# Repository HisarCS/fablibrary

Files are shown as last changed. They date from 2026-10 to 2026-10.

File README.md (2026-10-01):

# FabLibrary – Hisar FabLab

An open design library for the K12 Fab STEAM projects of Hisar IdeaLab FabLab.
Every project is documented here with its laser-cut, 3D-printed, electronics and teaching materials.

**Website:** https://hisarcs.github.io/fablibrary/

## Projects

| Project | Level | Status |
|---|---|---|
| [Welcome Space](projects/welcome-space/) – LED-lit spaceship (Mission 01) | Grade 4, 60 min | v1 prototype |

## Quick start

```bash
pip install -r requirements.txt
python projects/welcome-space/generators/build.py   # regenerate design files
mkdocs serve                                        # preview the site at http://127.0.0.1:8000
```

## License

- Design files and documentation: CC BY-SA 4.0 ([LICENSE-DESIGNS.md](LICENSE-DESIGNS.md))
- Code (generators, scripts): MIT ([LICENSE](LICENSE))

How to contribute: [CONTRIBUTING.md](CONTRIBUTING.md)

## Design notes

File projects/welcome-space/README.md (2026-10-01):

# Welcome Space – Mission 01

An LED-lit, personalized desktop spaceship. Grade 4, 60 minutes, ~140 students.

| Folder | Contents |
|---|---|
| `laser/` | Base plate, panel, wing, comb test (SVG, mm) |
| `3d/` | Nose cone, diffuser (OpenSCAD, parametric) |
| `drawings/` | Dimensioned technical drawings, assembly |
| `electronics/` | Electronics notes and test form |
| `stickers/` | BN-20 sticker files |
| `teaching/` | Lesson plan, troubleshooting card |
| `tests/` | Test photos and notes |
| `generators/` | Scripts that generate every SVG |
| `kit-list.md` | Parts per kit and post-test parameter map |

To regenerate (from repo root): `python projects/welcome-space/generators/build.py`

Website: https://hisarcs.github.io/fablibrary/projects/welcome-space/

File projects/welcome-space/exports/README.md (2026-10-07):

# Exports

Generated by `scripts/export_formats.py`. Do not edit these files by hand: edit the sources and run the script again.

| Folder | For | Notes |
|---|---|---|
| `inkscape/` | Inkscape | Named layers, millimetre display units |
| `illustrator/` | Adobe Illustrator | Plain SVG, each group becomes a layer |
| `dxf/` | Laser software, LightBurn, xTool, Epilog, any CAD | Layers CUT (red) and ENGRAVE (black), millimetres |
| `web/` | The website | Thicker lines and a white background, for thumbnails |
| `onshape/` | Onshape (and any CAD) | Flat profiles and the half-profiles of the revolved parts, for sketches. STL cannot be edited as CAD. |

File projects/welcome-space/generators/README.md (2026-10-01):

# Generators

All laser SVGs and drawings are generated by these scripts. Do not edit the SVGs by hand.

| Script | Generates | Key parameters |
|---|---|---|
| `base_diffuser_comb.py` | base plate laser, comb test, base + diffuser drawing | `SLOT_W`, `SLOT_L`, `WSLOT_L` |
| `panel_nosecone.py` | panel laser, panel + nose cone drawing, nose cone SCAD | panel profile `P` |
| `wing.py` | wing laser and drawing | wing profile `K` |
| `assembly.py` | assembly drawing | – |
| `printables.py` | GS-24 copper band, BN-20 sticker sheet, troubleshooting card | band layout, sticker positions |
| `student_card.py` | picture-first student step card (A4) | tile drawings, text |
| `model3d.py` | 3D preview meshes (STL) and web viewer data | needs numpy, scipy, matplotlib; not run by `build.py` |
| `model_b.py` | Model B (LEDs outside): laser SVGs, drawing, nose cone, preview STLs, viewer data | needs numpy, scipy, matplotlib; not run by `build.py` |
| `hero.py` | day/night and personalization illustrations | colors, `deco` styles |

`3d/v1_diffuser.scad` is a hand-maintained parametric file.

Run: `python projects/welcome-space/generators/build.py`

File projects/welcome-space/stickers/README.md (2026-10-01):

# Sticker set (BN-20)

One sheet per student, 15–20 pieces: 3 windows, 3 planets, 4–5 stars, 3 wing patterns, 1–2 stripes, 1 blank name label (optional).

Rules: no stickers on press-fit tab areas, on the nose cone/diffuser, or on the electronics area. Matte vinyl, kiss-cut.

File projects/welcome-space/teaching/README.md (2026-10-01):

# Teaching materials

Lesson plan: `docs/projects/welcome-space/lesson.md`

Troubleshooting card (5 steps): Battery → Switch → LED direction → Tape contact → Leg contact

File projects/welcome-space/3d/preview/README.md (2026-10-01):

# Preview meshes (not for printing)

These STL files are generated from the same numbers as the drawings by `generators/model3d.py`. They exist so that anyone can look at the design in a 3D viewer, a slicer preview or the website explorer.

- `v1_assembly_preview.stl`: the whole ship, assembled.
- One STL per part type: base plate, panel (1 of 3), wing (1 of 3), nose cone, diffuser.

They are **simplified**: the nose-cone slots and the diffuser switch window are not modeled. **Print from the OpenSCAD files** (`../v1_nose_cone.scad`, `../v1_diffuser.scad`). To export real print STLs:

```bash
sudo apt install openscad
openscad -o v1_nose_cone.stl ../v1_nose_cone.scad
openscad -o v1_diffuser.stl ../v1_diffuser.scad
```

Regenerate the previews (needs `numpy`, `scipy` and `matplotlib`):

```bash
pip install numpy scipy matplotlib
python projects/welcome-space/generators/model3d.py
```

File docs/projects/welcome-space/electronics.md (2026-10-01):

# Electronics

**One rule:** if the electronics are solid, everything else is artistic.

## Architecture
CR2032 → holder with cover and switch → 2 straight copper rails (+ on top, − on bottom) → 3 LEDs (2 white + 1 color). Everything sits on the **bottom face** of the base plate, inside the exhaust diffuser. Panels and nose cone carry no electrical connections.

## Rules
- Rails are 54 × 5 mm with an **8 mm** gap; extra tape pieces are 6 mm max (short-circuit prevention).
- LED legs: long (+) on the top rail, short (−) on the bottom rail. The leg lies flat on the rail and a short piece of copper tape goes on top (**sandwich joint**).
- The copper tape adhesive must be **conductive**: check with a multimeter from adhesive side to top side.
- If resistors are needed, assistants pre-solder them, not students. Values are set by testing; white/blue LEDs may be brighter without resistors on a CR2032.
- The internal resistance of a CR2032 limits short-circuit current; if switching to stronger cells (AAA), add a resettable fuse.

## Acceptance test
1. Open-circuit and loaded voltage on a fresh cell
2. Series current for each LED type
3. Cell voltage and brightness after 1 hour
4. All three LEDs visible from 3 m in a dark room
5. Switch cycled 100 times
6. 10 different people build the same circuit: **10/10 must work**

## Troubleshooting order
Battery → Switch → LED direction → Tape contact → Leg contact

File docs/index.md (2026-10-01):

# FabLibrary

An open design library for the K12 students of Hisar IdeaLab FabLab. Every project is a **mission**: first assemble, then modify, then design your own.

**Assemble → Modify → Design → Fabricate → Test → Improve**

Welcome Space spaceship with stickers, day and dark room

*Illustration of a finished ship.*

<div class="grid cards" markdown>

-   :material-rocket-launch: **Welcome Space** · Mission 01

    ---

    An LED-lit, personalized desktop spaceship. Laser cutting, 3D printing and solderless electronics in 60 minutes.

    Grade 4 · v1 prototype

    [:octicons-arrow-right-24: Go to project](projects/welcome-space/index.md)

-   :material-lock-clock: **Mission 02 – Modify**

    ---

    Design your own wing, cut it on the laser, attach it to your ship.

    Coming soon

-   :material-gamepad-variant: **Play the game** · Mission Control

    ---

    Six short missions on the iPad: match parts to machines, light the LEDs, hunt bugs and design your own ship.

    [:octicons-arrow-right-24: Play](projects/welcome-space/play.md)

</div>

## The path

| Mission | Idea | Status |
|---|---|---|
| 01 Assemble | Build and light your own spaceship from ready-made digital-fabrication parts | v1 prototype |
| 02 Modify | Change a part: your own wing shape | Planned |
| 03 Design | Design a part in CAD from scratch | Planned |
| 04 Fabricate | Cut and print your own design | Planned |
| 05 Improve | Test, find what to fix, make version 2 | Planned |

*Your first design does not have to be your last design.*

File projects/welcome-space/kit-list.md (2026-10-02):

# v1 Spaceship – Kit List and Parameter Map

Target: 140 students + spares and prototypes = **160 kits**. All values are v1 drafts and will be updated after testing.

## 1. Parts per kit

| # | Part | Qty/kit | Process | File | Total (160) |
|---|---|---|---|---|---|
| 1 | Base plate Ø110 | 1 | Laser, 3 mm birch | `laser/v1_base_plate_laser.svg` | 160 |
| 2 | Body panel | 3 | Laser, 3 mm birch | `laser/v1_panel_laser.svg` | 480 |
| 3 | Wing | 3 | Laser, 3 mm birch | `laser/v1_wing_laser.svg` | 480 |
| 4 | Nose cone | 1 | 3D, translucent PLA/PETG | `3d/stl/v1_nose_cone.stl` (export of `v1_nose_cone.scad`) | 160 |
| 5 | Exhaust diffuser | 1 | 3D, translucent PLA/PETG | `3d/stl/v1_diffuser.stl` (export of `v1_diffuser.scad`) | 160 |
| 6 | CR2032 holder with cover and switch | 1 | Off the shelf (Motorobit, sample pending) | – | 160 |
| 7 | CR2032 cell | 1 | Off the shelf | – | 160 |
| 8 | 5 mm LED, white | 2 | Off the shelf | – | 320 |
| 9 | 5 mm LED, color | 1 | Off the shelf | – | 160 |
| 10 | Copper rail set (2 rails 54×5 + 6 patches) | 1 | GS-24 cut or by hand | – | 160 |
| 11 | Resistor | 0–3 | Off the shelf, pre-soldered by assistants | Set by testing | TBD |
| 12 | Sticker sheet | 1 | BN-20 print + cut | To be designed | 160 |
| 13 | Double-sided tape (for holder) | 1 piece | Off the shelf | – | 160 |

## 2. Approximate materials (estimates, not measured)

| Material | Per kit | 160 kits |
|---|---|---|
| 3 mm birch plywood | ~0.06 m² (incl. 35% waste) | ~10 m² |
| Translucent filament | ~45 g (nose cone ~22 g + diffuser ~24 g, assuming 100% infill) | ~7.5 kg + test waste → **~9 kg** |
| 5 mm copper tape | ~0.3 m | ~50–60 m |

Print and laser times: **to be measured on the first part**, then split across 17 printers and 3 lasers.

## 3. Per class (outside the kit)

- Multimeter ×3, battery/LED tester ×2–3, tweezers ×5–6
- Spare finished rockets ×5–6
- Spare LEDs, cells, copper tape and stickers (15%)
- Troubleshooting card (5 steps: battery → switch → LED direction → tape contact → leg contact)

## 4. Parameters to change after testing

| Test | Value to measure | File and parameter to change |
|---|---|---|
| Comb test | Best slot width (3.00–3.30) | `generators/base_diffuser_comb.py`: `SLOT_W` (now 3.1) |
| Comb test | Same value | Panel bottom tab 27.8 and wing tab 19.8 (shorten if needed) |
| Nose cone print | Which of 3.2 / 3.3 / 3.4 fits | `3d/v1_nose_cone.scad`: `slotW` |
| Diffuser print | Which of 110.25 / 110.40 / 110.55 fits | `3d/v1_diffuser.scad`: `pocketD` |
| Holder sample | Switch side, height, wire exit | `3d/v1_diffuser.scad`: `winAng`, `winW`, `winZ0`, `winZ1` |
| Electronics bench test | LED type, resistor value, current | This list: #8, #9, #11 |
| Dark room | Does the nose cone glow? | LED direction or `wall` if needed |
| Wing wobble | Does it lean? | Split the wing tab in two |
| Child assembly | Order of steps 4-5-6 | `generators/assembly.py` |

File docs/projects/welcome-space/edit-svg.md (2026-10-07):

# Editing the SVG files

The laser, Roland and drawing files are plain SVG. You can open and edit them in any vector editor. This page shows how to do it safely.

## Which program?

| Program | Cost | Good for |
|---|---|---|
| **Inkscape** | free | Everything on this page. Recommended. Ubuntu: `sudo apt install inkscape` |
| Illustrator, CorelDRAW | paid | Fine, if your laser software is built on them |
| xTool Creative Space, LightBurn | | Open the SVG directly to cut it. Edit in Inkscape first for bigger changes |
| A text editor | free | Change a number or a word. SVG is just text |

## The rules every file follows

| Rule | Why |
|---|---|
| **1 unit = 1 mm.** Size is written in mm (for example `110mm`), and the `viewBox` has the same number. | The file cuts at real size. Keep the document scale at 100%. |
| **Red hairline = cut through.** Line width about 0.1 mm. | Laser software reads thin red as a cut. |
| **Black = engrave.** | Text, marks and guides on the surface. |
| **Magenta `CutContour` = the BN-20 cut line**, with the colors on a separate `PRINT` layer. | The Roland prints the colors and cuts along the magenta line. |
| Each file has named layers: **CUT**, **ENGRAVE** (and **PRINT**, **CUT CONTOUR** for stickers). | Open Inkscape's Layers panel (`Shift+Ctrl+L`) to hide or lock them. |

## Edit, step by step (Inkscape)

1. Open the file. If Inkscape asks about scale, choose the default and keep **mm** as the display unit (Document Properties, `Shift+Ctrl+D`).
2. In the Layers panel, **lock the CUT layer** while you edit the ENGRAVE layer (and the other way round), so you do not move the wrong thing.
3. Make your change. To move or resize something exactly, use the X, Y, W, H boxes in the toolbar, in mm.
4. **Convert text to outlines** before it goes to the machine: select the text, then *Path > Object to Path* (`Shift+Ctrl+C`). Otherwise the machine may use a different font.
5. Save as **Plain SVG** or **Inkscape SVG**, into `projects/welcome-space/custom/` (see below).
6. **Check it** before cutting:

   ```bash
   python scripts/svg_tool.py check projects/welcome-space/custom/your_file.svg
   ```

   It checks scale, colors, line width and text, and says what is wrong.

## Important: where to save your edit

Most SVGs here are **generated** from numbers (`generators/`). If you save your edit over the original, the next rebuild overwrites it.

- **A one-off edit** (a name engraved on one plate, a test piece): save it in **`projects/welcome-space/custom/`** with the name `<original>__custom-<what-you-changed>.svg`. That folder is never overwritten.
- **A real improvement** (a better slot width, a new hole): change the **parameter** in the generator, rebuild, and open an issue. Then every file and the 3D explorer update together.

## Quick fixes in a text editor

| I want to | Change |
|---|---|
| Change the plate diameter | The `r="55"` of the circle in the CUT layer (radius, in mm) |
| Make slots wider | The `height` or `width` of the slot rectangles. The generator parameter is `SLOT_W` |
| Move a label | The `x` and `y` of its `<text>` |
| Hide a layer in the machine software | Delete the layer's `<g> ... </g>` block |

## Check list before you cut

- [ ] `svg_tool.py check` says no errors
- [ ] Measure the finished file's size in the machine software: **110 mm** for a plate, with calipers on the first test piece
- [ ] Text is converted to outlines
- [ ] Red = cut, black = engrave, nothing else
- [ ] First cut on scrap plywood

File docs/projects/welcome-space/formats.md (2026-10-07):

# Files for Inkscape, Illustrator and Onshape

The same designs, in the format your program wants. All of them are generated from the sources by `scripts/export_formats.py`, so they always match. They live in the repository folder [`projects/welcome-space/exports`](https://github.com/HisarCS/fablibrary/tree/main/projects/welcome-space/exports) and in the [Source files](sources.md) ZIP.

## Which folder for which program

| I use | Take the files from | What you get |
|---|---|---|
| **Inkscape** | `exports/inkscape/*.svg` | Named layers (CUT, ENGRAVE, PRINT), millimetre display units |
| **Adobe Illustrator** | `exports/illustrator/*.svg` | Plain SVG. Each group becomes a layer named CUT-..., ENGRAVE-... |
| **Laser software** (Epilog, xTool Creative Space, LightBurn) | `exports/dxf/*.dxf` or the Illustrator SVG | DXF with layers CUT (red) and ENGRAVE (black), in millimetres, text kept as text |
| **Onshape** (or any CAD) | `exports/onshape/*.dxf` | Flat profiles and half-profiles for sketches (see below) |
| **A slicer** (Bambu Studio) | `3d/stl/*.stl` | The print-ready meshes |
| **OpenSCAD** | `3d/*.scad` | The parametric source of the 3D printed parts |

!!! warning "Test one file first"
    Every program reads SVG and DXF a little differently. Open one file, measure it against the drawing (a plate must be **110 mm**), then cut a test piece on scrap plywood. Convert text to outlines before it goes to the laser.

## Onshape: what you can and cannot do

- **An STL is only a mesh.** Onshape can show it and measure it, but you cannot change a hole or a width in it. Keep STL for printing and fit checks.
- **To get an editable Onshape model, import the DXF sketches and build the part from them.** Then every dimension is yours to change.

Import a DXF into a Part Studio so that its lines become a sketch, and set the units to **millimetres**. (The names of Onshape's menus change from time to time, so look for "import a DXF into the Part Studio as a sketch".)

### Flat parts (laser cut): extrude 3 mm

| File | Extrude | Notes |
|---|---|---|
| `v1_base_plate_profile.dxf` | the disc, **3 mm** | The circle is the outline, the six rectangles are the slots (3 panel + 3 wing), keep them as holes |
| `v1_panel_profile.dxf` | **3 mm** | Contains the 3 panels: use one |
| `v1_wing_profile.dxf` | **3 mm** | Contains the 3 wings: use one |
| `v1b_base_plate_profile.dxf` | the disc, **3 mm** | Plate for Model B: 3 panel slots, 3 wing slots, 2 wire holes |
| `v1b_panels_set_profile.dxf` | **3 mm** | 3 panel outlines (1 power + 2 plain): use one |
| `v1b_wing_profile.dxf` | **3 mm** | 3 wings: use one |

### Round parts (3D printed): revolve 360 degrees

Each DXF holds the half-profile and a straight line called AXIS. Revolve the profile around the AXIS line.

| File | Revolve | Then add |
|---|---|---|
| `v1_diffuser_profile.dxf` | one closed profile | A window 14 mm wide through the wall at 180 degrees, from 8 to 18 mm above the table (parameters in `3d/v1_diffuser.scad`) |
| `v1_nose_cone_profile.dxf` | two closed profiles: the shell and the hub | 3 pockets 9 x 3.3 mm, radial, 11 mm deep, at 90 / 210 / 330 degrees |
| `v1b_nose_cone_profile.dxf` | the shell and the hub | 3 pockets 12.4 x 3.3 mm, **tangential**, 10 mm deep, at radius 15 mm, at 90 / 210 / 330 degrees |

The curved line of a nose cone is part of an ellipse. The DXF stores it as many short lines. To make it cleaner in Onshape, replace it with an ellipse: Model A has semi-axes **23 and 45 mm**, Model B **33 and 50 mm**, wall 1.2 mm.

### Where the parts sit (Model A, millimetres above the table)

| Part | Position |
|---|---|
| Diffuser | z 0 to 24 |
| Base plate | z 21 to 24 (flush with the top of the diffuser) |
| Panels | stand on the plate (z 24), 130 tall, tab 2.5 mm into the plate, 10 mm tab up into the nose cone |
| Nose cone | base at z 154, 45 tall |
| Wings | tab 2.5 mm into the plate, outer part hangs 18 mm below the plate top |

Model B: panels are 125 tall, the nose cone base is at z 149 and it is 50 tall.

## How these files were checked

The DXF files were read back with a separate reader and drawn: the plate slot is 28 x 3.1 mm, the plate is 110 x 110 mm, the nose cone profile is 23 wide and 45 tall. They were **not opened in Onshape, Illustrator, LightBurn or the laser programs**. Please test one file in your program and report problems in an issue.

## How to regenerate

After you change a parameter:

```bash
python projects/welcome-space/generators/build.py
python projects/welcome-space/generators/model_b.py
python scripts/svg_tool.py prepare
python scripts/export_formats.py
```

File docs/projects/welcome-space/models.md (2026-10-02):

# Model A or Model B?

Two versions of the same ship. The lesson, the diffuser, the battery holder, the LEDs and the stickers are shared. Only the body and the place of the electronics differ. The lab team builds both and decides with the same tests.

[Compare them in the 3D explorer](viewer/index.html?m=b){ .md-button .md-button--primary }
(use the **Model A / Model B** buttons)

## What is different

| | **Model A: under the plate** | **Model B: LEDs outside** |
|---|---|---|
| Body | 3 radial panels (open, Y shaped) | 3 panels in a triangle (closed) |
| LEDs | Under the plate, shining down into the diffuser | On one "power panel", shining outward |
| Copper rails | 2 straight rails, 54 mm, under the plate | 2 straight vertical rails, 106 mm, on the power panel |
| Wires | None | 2 short wires from the holder, up through the plate, to the rail bottoms |
| Battery holder | Under the plate | Under the plate (same) |
| Panels | 3 identical | 2 plain + 1 power panel |
| Sticker area per panel | small (about 13 to 46 mm wide) | large (46 x 120 mm) |
| Nose cone | 46 mm, glows a little (estimate) | 66 mm, decoration only |
| Diffuser | Glows | Does not glow (LEDs are outside) |
| What the student sees | The circuit while the plate is upside down, then it is hidden | The LEDs and the copper tape all the time |
| Electrical joints | LED legs on one flat plate | LED legs (6) and wire ends (2) on a vertical panel |

## Why B is worth testing
- It matches the original brief: LEDs facing outward, straight rails, closed body with room for stickers.
- The student can see the circuit working, and can troubleshoot by looking.

## Why B can fail (unverified)
- **Wires and joints.** Eight joints on a vertical panel handled by children. Wires can pull off the rails.
- **LED hold.** The LED stands on its folded legs under two copper patches. It may tip or lift.
- **Corner slits.** The panels meet at 60 degrees with a gap of a few millimetres at each corner.
- **Panels wobble** until the nose cone locks the top tabs.
- **Bigger nose cone** (66 mm) uses more plastic and print time.
- **Fewer parts under the plate, more on the outside**, so more things can be bumped.

## Parts needed for B (differences only)

| Part | Note |
|---|---|
| Base plate B | [v1b_base_plate_laser.svg](files/v1b_base_plate_laser.svg){ download } |
| Panel set: 1 power panel + 2 plain | [v1b_panels_set_laser.svg](files/v1b_panels_set_laser.svg){ download } (cut one set per ship) |
| Wings (3) | [v1b_wing_laser.svg](files/v1b_wing_laser.svg){ download } |
| Nose cone B | `3d/v1b_nose_cone.scad`, [v1b_nose_cone.stl](files/v1b_nose_cone.stl){ download } |
| Copper band for the GS-24 (3 kits per band) | [v1b_copper_rails_gs24_cut.svg](files/v1b_copper_rails_gs24_cut.svg){ download } |
| 2 thin flexible wires, about 12 cm, red and black, 5 mm stripped ends | about 24 to 26 AWG, to be confirmed on the bench |
| Diffuser | The same part as Model A |

Model B drawing

## Build order for B

1. Stickers on the flat panels and wings.
2. Stick the two rails on the power panel (follow the engraved lines).
3. Place the three LEDs, long leg on the **+** rail, and press a copper patch over every leg.
4. Battery holder under the plate. Push the two wires up through the two holes.
5. Stand the power panel in its slot. Press each wire end onto the bottom of its rail with a patch.
6. Switch ON and test. Not lit? Battery, switch, LED direction, tape contact, LED legs.
7. Stand the two plain panels in the slots, put the nose cone on the top tabs.
8. Wings into the short slots at the corners.

## How we decide

Both models must first pass the **electronics gate**: 10 builds, 10 working ships. A model that fails the gate is out, whatever its score.

Then score each model from 1 (bad) to 5 (very good) on the lab's priorities. The weight is the priority rank.

| Priority | Weight | How to measure |
|---|---|---|
| 1. Reliability | 8 | Gate result, and joints still working after a gentle shake and a gentle tug on the wires |
| 2. A child can build it alone | 7 | Share of volunteers who finish without help |
| 3. Fits in 60 minutes | 6 | Build time (adult 15 to 20 min, child 35 to 45 min) |
| 4. Easy to troubleshoot | 5 | Time for a helper to find a planted fault |
| 5. Scales to 140 ships | 4 | Cut and print time per kit, number of parts, joints per ship |
| 6. FabLab processes are visible | 3 | Does the student see what each machine made? |
| 7. Looks great | 2 | Dark-room look from 3 m |
| 8. Makes children curious about CAD | 1 | Pilot feedback |

Weighted total = sum of (score x weight). Write the scores in the **A/B decision** issue, and use the CSV templates in `projects/welcome-space/tests/`.

## Tests to run on both models

| Test | What to record |
|---|---|
| Build time with an adult, 5 ships each | Minutes, first-try success |
| Gate: 10 builds | How many light all 3 LEDs |
| Shake and tug | Do all LEDs stay lit? Which joint failed? |
| Stands upright | Wobble before and after the nose cone |
| Dark room, 3 m | Are 3 LEDs visible? Is the nose cone lit (A)? |
| Cell change and switch | Easy to reach? |
| Planted fault | Minutes for a helper to find it |

## Assumptions to check for B

| ID | Assumption | Status |
|---|---|---|
| B1 | Wire ends stay on the rails under a copper patch | Assumed |
| B2 | An LED stands on folded legs under two patches without tipping | Assumed |
| B3 | A 2 mm gap at each panel corner looks acceptable (or can be hidden with a sticker) | Assumed |
| B4 | The triangle of panels stands once the nose cone is on | Assumed |
| B5 | A 4 mm wire hole is enough for a thin silicone wire | Assumed |
| B6 | The 66 mm nose cone prints in about the same time as the 46 mm one | Assumed |

Record the decision in the [assumptions log](assumptions.md) and in `CHANGELOG.md`.

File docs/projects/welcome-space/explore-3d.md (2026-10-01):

# 3D explorer

Turn the whole ship around, pull it apart, cut it in half and look at the electronics under the plate. It works on an iPad.

[Open the 3D explorer full screen](viewer/index.html){ .md-button .md-button--primary }

<iframe src="../viewer/index.html" title="3D explorer" width="100%" height="640" style="border:1px solid var(--md-default-fg-color--lightest);border-radius:12px" loading="lazy"></iframe>

## How to use it

| Control | What it does |
|---|---|
| Drag | Turn the ship |
| Pinch or scroll | Zoom in and out |
| Double-tap | Reset the view |
| **Explode** slider | Pull all parts apart |
| **Cut in half** | Slice the ship through the middle to see inside |
| **Lights on** | Night mode: the LEDs glow in the diffuser |
| **Under** | Look from below, at the electronics |
| Part names | Tap to hide or show a part and read what it is |
| **Model A / Model B** | Switch between the two designs. See [Model A or Model B?](models.md) |

## What to look for

- **Model A:** the electronics are only under the base plate: the copper rails, the battery holder with its switch and the three LEDs.
- **Model B:** the holder is under the plate, two wires come up through the plate to the copper rails on the power panel, and the LEDs face outward.
- Panels and wings are different parts. Their slots are different lengths, so they cannot be mixed up.
- Hide the panels and the nose cone to see how the plate, the rails and the diffuser fit together.

## Download the meshes

The same model is available as STL files in the repository: [`3d/preview`](https://github.com/HisarCS/fablibrary/tree/main/projects/welcome-space/3d/preview). Open them in any 3D viewer or slicer preview.

!!! warning "Preview, not for printing"
    The model is built from the numbers in the drawings and simplified: the nose-cone slots and the diffuser switch window are not shown. Print from the OpenSCAD files. Real shape and fit are confirmed only after the first prototype is built.

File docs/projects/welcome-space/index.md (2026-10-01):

# Welcome Space – Mission 01

!!! warning "Draft v1: nothing has been physically tested yet"
    All dimensions are estimates. Check the Assumptions page and the First week plan before cutting or printing.

The first project where grade 4 students meet the FabLab. In 60 minutes, every student builds an LED-lit spaceship they personalize themselves and take home.

**Digital Design → Digital Fabrication → Electronics → Assembly → Testing → Functional Product**

The finished v1 ship, by day and in a dark room

*Illustration of a finished v1 ship with its stickers applied. The nose cone brightness is an estimate and will be verified in the dark-room test.*

## Make it yours

Every student gets one sticker sheet (printed and cut on the Roland BN-20): 3 window stickers, 3 planets, 5 stars, 3 wing patterns, 2 stripes, a blank name label and a Bug Hunter badge. The pink line is the cut contour.

Sticker sheet

Same sheet, three different ships:

Three personalized ships

## How it goes together

Assembly

## Status

| Area | Status |
|---|---|
| Design | v1 draft complete |
| Tolerances | Waiting for comb test |
| Electronics | Waiting for battery holder samples |
| Pilot | Not scheduled |

## Design principles

- Electronics in **one place**: under the base plate, on a single face, tested before mechanical assembly.
- Glue-free press-fit, solderless circuit, few parts.
- Poka-yoke: panel slot 28 mm, wing slot 20 mm; the wrong part does not fit the wrong slot.
- Mistakes are instructive, not destructive.

## Scale

6 classes, ~140 students, 160 kits (spares included). Details: [kit list](kit-list.md). Before building with children, read the [safety notes](safety.md).

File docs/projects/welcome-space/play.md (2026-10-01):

# Play: Mission Control

**A game for iPad.** Every part of this spaceship was made in the Hisar IdeaLab FabLab. In Mission Control you learn how, by playing six short missions.

[Play the game](game/index.html){ .md-button .md-button--primary }

!!! tip "Put it on the iPad home screen"
    Open the game in Safari, tap the **Share** button, then **Add to Home Screen**. It opens like an app, full screen.

## The six missions

| # | Mission | You learn | Same idea in the real lesson |
|---|---|---|---|
| 1 | **Fab Match** | Which machine makes which part: laser, 3D printer, Roland GS-24, Roland BN-20, electronics bench | The "which part was made on which machine?" question at the start |
| 2 | **Circuit Lab** | A circuit needs a cell, a switch, and LEDs the right way round. The long LED leg goes to + | Placing LEDs on the copper rails |
| 3 | **Bug Hunter** | Observe, guess, check, fix, test again. Look at the pattern of dark lights to find the cause | The troubleshooting card |
| 4 | **Tolerance Lab** | Why parts need a little gap, why every plywood is different, why we run a comb test | Press-fit "kid-fit" |
| 5 | **Build Order** | Flat parts first, test electronics before building the body, wings last | The 8 assembly steps |
| 6 | **Launch Pad** | Design a ship, see it glow in the dark, explore how LEDs change battery time | Dark-room finale and Mission 02 |

## For teachers

- **Before the lesson:** Mission 1 (Fab Match) makes a good warm-up for the first question of the lesson.
- **After the lesson:** missions 2–6 reinforce what students did by hand. Mission 3 pairs with the troubleshooting card.
- **Not graded.** Stars are for fun. There are no accounts, no names and no tracking.
- The numbers in the game (slot sizes, battery hours) are **game numbers**. The real values come from the lab's tests.
- Tolerance Lab and Power Lab are deliberate previews of design thinking: *change a number, see what happens.* That is the bridge to Mission 02.

## Privacy

The game runs entirely in the browser. It sends nothing anywhere. The only thing stored is how many stars you earned, on this iPad only. The ship name is never saved, and the game asks students not to use their real name.

## For the lab team

The game is a single file: `docs/projects/welcome-space/game/index.html`. It has no external libraries, so it works offline once loaded. Edit it like any other file. Test it on a real iPad in portrait and landscape before every class.

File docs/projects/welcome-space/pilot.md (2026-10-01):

# Pilot lesson: observation form

Run the pilot with **6–8 students** in one 60-minute session, with two adults observing. Print this page or fill it in on a laptop. Do **not** write student names: use the pilot code printed on the base plate or a number.

Gate for the lesson: at least **80% of students** finish a working ship within 60 minutes.

## 1. Session

| Field | Value |
|---|---|
| Date and class | |
| Students / adults in the room | |
| Kits used (with spares) | |
| Cells counted in / out | / |
| Covers closed and checked before leaving the table | yes / no |
| Observer names (adults only) | |

## 2. Timeline

Write the real clock time when each phase starts and ends.

| Phase | Planned | Real start | Real end | Notes |
|---|---|---|---|---|
| Show finished ship, question | 0–7 | | | |
| FabLab intro | 7–12 | | | |
| Stickers | 12–20 | | | |
| Copper rails | 20–32 | | | |
| LEDs and polarity check | 32–42 | | | |
| Battery, ON, test, troubleshooting | 42–48 | | | |
| Mechanical assembly | 48–55 | | | |
| Lights off, all together | 55–60 | | | |

## 3. Per student (one row each)

Use the CSV template `pilot-log-template.csv`, or tick here.

| Code | Total minutes | Worked on first try? | Needed an adult? | Step where stuck | Fixed it by themselves? |
|---|---|---|---|---|---|
| | | | | | |
| | | | | | |
| | | | | | |
| | | | | | |
| | | | | | |
| | | | | | |

## 4. What went wrong (tally each time you see it)

| Problem | Count |
|---|---|
| Cell in the wrong way or switch left OFF | |
| LED in backwards | |
| Copper tape lifted or wrinkled | |
| Copper tape patch bridging both rails | |
| LED leg not touching the tape | |
| Panel slot too tight (needed force) | |
| Panel slot too loose (wobbles) | |
| Panels fell over before the nose cone was on | |
| Wing leans or came out | |
| Nose cone does not fit | |
| Sticker on a tab, on the plate edge or on the electronics area | |
| Other | |

## 5. The ship

- Does it stand upright on the table, without wobbling?
- Can a child change the cell and reach the switch easily?
- Dark room: are all three LEDs clearly visible from 3 m?
- Is the nose cone visibly lit? (assumption A10)
- Photos taken (no student faces): yes / no

## 6. Student survey (3 questions, 1 minute)

Ask at the end. One tick each: 1 = not really, 2 = a bit, 3 = yes!

| Statement | 1 | 2 | 3 |
|---|---|---|---|
| I made something that works. | | | |
| I can tell a friend what the lab machines do. | | | |
| I want to design my own part next time. | | | |

Optional: *"What would you change on your ship?"*

## 7. Adult debrief (10 minutes after the lesson)

1. Which step cost the most time?
2. Which instruction did students not understand?
3. Which tolerance or part should change before the next class?
4. Was the adult-to-student ratio enough? Where did you wish for a fourth adult?
5. Gate: did 80% finish within 60 minutes?

## 8. Decisions

Record them in a **Test result** issue, change parameters in a pull request and update the [assumptions log](assumptions.md).

| Decision | Owner | Issue |
|---|---|---|
| | | |

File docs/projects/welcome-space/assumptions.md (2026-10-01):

# Assumptions log

For planning, we **assume all ordered parts have arrived** and all machines work as expected. Each row below is something the design currently depends on but nobody has verified yet. When a test confirms or breaks an assumption, change its status and link the issue.

Status: **Assumed** (not verified) · **Confirmed** · **Broken** (design must change)

| ID | Assumption | Used in | Verify with | Status |
|---|---|---|---|---|
| A1 | Parts orders (holders, LEDs, resistors, multimeters, copper tape) arrive on time | Whole plan | Week 1, Day 1 order issue | Assumed |
| A2 | The Motorobit "CR2032 holder, cover and switch, transparent" is 24 × 34 × 6.2 mm, has wire leads, and the switch and cover are reachable from below | Base plate footprint, diffuser window | Holder sample on arrival | Assumed |
| A3 | A child cannot easily open the holder cover; the cell stays inside | Safety | Hand test with 5 samples | Assumed |
| A4 | The switch survives 100 on/off cycles | Electronics | Bench test | Assumed |
| A5 | The 5 mm copper tape has conductive adhesive (adhesive side to foil side reads as conductive) | Rails, patches | Copper tape check, Day 1 | Assumed |
| A6 | A CR2032 lights white and blue 5 mm LEDs well enough without resistors; 15–25 h of running time | LED set, resistor decision | Bench test, Day 3 | Assumed |
| A7 | Real plywood thickness is 3.0 mm | All slots | Caliper measurement | Assumed |
| A8 | `SLOT_W` 3.1 mm works as a child-friendly fit | Base, panel, wing | Comb test, Day 1 | Assumed |
| A9 | Nose cone `slotW` 3.3 mm and diffuser `pocketD` 110.4 mm fit | 3D parts | 3D test prints, Day 2 | Assumed |
| A10 | Light from the LEDs under the plate reaches and visibly lights the nose cone | Dark-room look | Dark-room test, Day 4 | Assumed |
| A11 | A panel held by one 28 mm tab stands upright once the nose cone is on | Mechanics | Integrated prototype, Day 4 | Assumed |
| A12 | A wing held by one 20 mm tab does not lean or snap | Mechanics | Integrated prototype, Day 4 | Assumed |
| A13 | The GS-24 can feed a 50 mm wide conductive copper roll and thin rails can be weeded; otherwise rails are cut by hand with a jig | Copper band file | GS-24 test, Day 5 | Assumed |
| A14 | BN-20 stickers stick to bare birch plywood and peel cleanly | Sticker sheet | BN-20 test, Day 5 | Assumed |
| A15 | An adult builds a ship in 15–20 min; a child needs 35–45 min | Lesson plan | Integrated prototype, then pilot | Assumed |
| A16 | Filament use is about 45 g per kit (upper bound, 100% infill) | Kit list | First print | Assumed |

## How to update this page

1. Run the test and record it in a *Test result* issue.
2. Change the status in this table and link the issue number.
3. If an assumption is **Broken**, open a pull request that changes the design parameters, and add a line to `CHANGELOG.md`.

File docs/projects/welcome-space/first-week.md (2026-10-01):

# First week plan

Goal of the week: **know the real numbers.** Every task ends with a GitHub issue (*Issues → Test result*) containing the measured value, a photo (no student faces) and a decision. Parameters are changed only through a pull request.

Roles: **Lead** (decisions, ordering), **Production** (laser, 3D printers, Roland), **Electronics** (bench tests, class support).

| Day | Role | Task | Done when |
|---|---|---|---|
| 1 | Lead | Order samples: 5 × CR2032 holders with cover and switch (both "single" models), 2 × 2×AAA holders with switch, LED assortment (white, blue, red, green, yellow), resistor set (22, 47, 100, 150, 220 Ω), 3 multimeters, conductive copper tape | Order placed, delivery dates noted in the issue |
| 1 | Production | **Comb test**: cut `v1_comb_test_laser.svg` on the Epilog and on an xTool, from the real plywood. Try each slot with a plywood tab, find the width that slides in by hand without force and does not wobble | Best width for each machine recorded (3.00–3.30 mm) |
| 1 | Electronics | **Copper tape check**: multimeter from the adhesive side to the foil side on 5 spots of each roll | Conductive or not, per roll |
| 2 | Production | **3D test prints**: nose cone with `slotW` 3.2 / 3.3 / 3.4, diffuser with `pocketD` 110.25 / 110.40 / 110.55 (translucent PLA and PETG if possible). Note print time and filament per part | Best values and print times recorded |
| 2 | Lead | Review comb test result, open the pull request that sets `SLOT_W` (base plate, panel tab, wing tab) | PR merged, generators rebuilt |
| 3 | Production | Cut the first full laser set with the new values (base, 3 panels, 3 wings). Sand edges lightly | One complete set, photo |
| 3 | Electronics | **Bench test** when the samples arrive: CR2032 holder + 2 rails + 3 LEDs on a plywood scrap. Measure open-circuit and loaded voltage, current per LED type, brightness | Table of LED type vs. current and brightness |
| 4 | All | **Integrated prototype**: an adult builds one ship following only the assembly drawing, timed with a stopwatch. Test the order of assembly steps 4-5-6 | Time recorded (target 15–20 min), problems listed |
| 4 | Electronics | **Dark-room test**: all three LEDs visible from 3 m? How bright is the nose cone? | Photos and verdict |
| 5 | Production | **GS-24** copper cut test (10 cuts of the two rails) and **BN-20** sticker test on bare plywood: adhesion, clean peel, no ink bleed | 10/10 clean cuts, sticker verdict |
| 5 | Lead | Review all issues, decide: first pilot date, which parameters to freeze, what to re-test | Written decision in the issue tracker |

## Rules

- Do not change a design file by hand. Change the parameter in `projects/welcome-space/generators/`, run `build.py`, open a pull request.
- If a gate fails, that is a useful result. Record it, do not hide it.
- The holder samples may arrive late: do the tasks that do not depend on them first (comb test, copper tape check, 3D test prints).
- Keep one tray for all small parts and count coin cells in and out.

## Gate criteria

| Test | Pass |
|---|---|
| Comb test | Slides in by hand, no force, no wobble |
| 3D prints | Nose cone and diffuser both fit |
| Electronics | 10 circuits out of 10 light all three LEDs |
| Integrated prototype | Adult builds it in 15–20 minutes |
| Dark room | Three LEDs seen from 3 m |

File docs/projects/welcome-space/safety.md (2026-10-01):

# Safety

This project is built with children, so safety comes before everything else. These are practical notes for the lab team, not a substitute for your school's own safety rules.

## Coin cells (CR2032)

- **A swallowed coin cell is a medical emergency.** If a child may have swallowed a cell, get emergency medical help immediately (112 in Türkiye). Do not wait for symptoms.
- Assistants load the cells, not the students. Cells stay in a counted box until the test step.
- Close the holder cover before the ship leaves the table. Check that the cover cannot be opened by a child without effort.
- Never short-circuit, heat, crush or recharge a coin cell. Keep used cells in a collection box and dispose of them as battery waste.
- Count cells in and out for every class.
- Tell students: the cell never goes in the mouth, nose or ears, and a loose cell goes straight to an adult.

## LEDs and wiring

- Use only the 3 V cell. Do not swap in stronger batteries (AAA or larger) without adding a resettable fuse, as described on the [Electronics](electronics.md) page.
- If anything gets warm, switch off and remove the cell. Tell an adult.
- Check the bench with a multimeter before the first class: wrong parts cause most failures.
- Thin copper foil has sharp edges: cut tape with scissors or a cutter on the table, not in the hand.

## Machines (adults only)

- Children never operate the laser cutters, 3D printers or Roland machines. Demonstrations happen with the lid closed and behind a line.
- Laser cutting needs working ventilation and fire attention, with an adult at the machine at all times.
- Hand out 3D printed parts only after they have cooled.
- Remove burnt edges and splinters: lightly sand laser-cut plywood before it reaches students.

## Small parts and waste

- Count small parts (LEDs, cells, tape pieces) before and after each class. Keep them out of mouths and off the floor.
- Provide a small tray per student for leftovers.

## Supervision

About 23 students per class with 3 adults. Peer check for LED direction is part of the lesson, but an adult confirms every circuit before the cell goes in.
- Do not use student faces, names or class information in photos taken during the lesson.

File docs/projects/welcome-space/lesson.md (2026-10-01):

# Lesson plan (60 min)

| Minutes | Activity |
|---|---|
| 0–7 | Show a finished ship: "Which part was made on which machine?" |
| 7–12 | FabLab intro: laser, 3D printer, Roland, electronics. A short live laser cut. |
| 12–20 | Personalization: choosing and applying stickers |
| 20–32 | Copper rails |
| 32–42 | LEDs, polarity check (peer check) |
| 42–48 | Battery, ON, test, troubleshooting |
| 48–55 | Mechanical assembly |
| 55–60 | Lights off, all ships light up together |

Closing message: *"Today you assembled the parts you were given. In the next mission, you will design some of them yourself."*

## Classroom setup
- ~23 students, 3 adults. 5–6 spare finished rockets.
- A "Bug Hunter" sticker for every student who fixes their own circuit.

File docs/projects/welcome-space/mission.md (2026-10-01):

# Mission: How was this spaceship made?

:material-rocket-launch: Your ship was made by four different machines working together!

| Part | Machine | What did it do? |
|---|---|---|
| Body, wings, base | Laser cutter (Epilog, xTool) | Cut the wood with light and drew lines on it |
| Nose cone and exhaust | 3D printer (Bambu Lab) | Melted plastic layer by layer into shape |
| Copper rails | Roland GS-24 | Cut the copper tape with a blade |
| Stickers | Roland BN-20 | Printed and cut them |
| Light | You! | You built the circuit and lit the LEDs |

## Did you know?
The **long leg of an LED goes to plus (+)**, the short leg to minus (−). If you put it in backwards, it won't light, but it won't break either. Find it and fix it, and you become a **Bug Hunter**!

## Next mission
**Mission 02 – Modify:** You will design your own wing, cut it on the laser and attach it to your ship.

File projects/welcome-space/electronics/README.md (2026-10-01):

# Electronics

Details: `docs/projects/welcome-space/electronics.md`

Record test results with GitHub Issues → Test result.

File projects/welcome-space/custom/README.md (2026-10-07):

# Your own edited SVG files

Put hand-edited SVGs here. **Nothing in this folder is overwritten** by the generators or by `build.py`.

Name them after the original plus what you changed:

```
v1_base_plate_laser__custom-wider-slots.svg
v1_panel_laser__custom-name-engraving.svg
```

Before cutting, check the file:

```bash
python scripts/svg_tool.py check projects/welcome-space/custom/your_file.svg
```

If your edit is a **better design** (not just a one-off), say so in an issue and change the parameter in the generator instead, so everyone gets it.

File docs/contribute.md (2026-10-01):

# Contribute

This library is developed by the Hisar FabLab team. Workflow for assistants:

1. Test → **Issues → Test result** form
2. Change → new branch, change the parameter in the generator script, run `build.py`
3. Update `CHANGELOG.md`
4. Pull Request → approval → the site updates automatically

Want to make this in your own FabLab? All files are open under CC BY-SA 4.0. Just credit the source.

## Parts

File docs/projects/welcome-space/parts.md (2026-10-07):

# Parts and files

**Everything for this project is on this page:** every part, every file format, the 3D models, the sources and the tools. Click a picture to see it large.

[Download everything as one ZIP](files/welcome-space-sources.zip){ .md-button .md-button--primary download }
[Open the full file list](sources.md){ .md-button }

The ZIP holds every editable file and keeps the repository folder layout. It leaves out the generated bulk (3D explorer data and preview meshes), which the generators rebuild.

## Pick your program

| I use | Take | Where on this page |
|---|---|---|
| **Inkscape** | the Inkscape SVG | "Open it in" column of every laser, Roland and sticker file |
| **Adobe Illustrator** | the Illustrator SVG | same column |
| **Laser or Roland software** (Epilog, xTool, LightBurn, CutStudio) | the DXF or the Illustrator SVG | same column |
| **Onshape or other CAD** | the Onshape sketch (DXF) | same column, and the 3D printed parts table |
| **A slicer** (Bambu Studio) | the STL | 3D printed parts |
| **OpenSCAD** | the `.scad` source | 3D printed parts |
| **Just looking** | the picture, or the 3D explorer | pictures below, [3D explorer](explore-3d.md) |

How the formats differ, and how to build an editable Onshape model: [Files for Inkscape, Illustrator and Onshape](formats.md). How to edit SVG files safely: [Editing the SVG files](edit-svg.md).

!!! warning "Tolerances are estimates"
    All dimensions are estimates until the first tests. Open one file in your own program, measure it (a plate must be **110 mm**), then cut a test piece on scrap plywood. Convert text to outlines before it goes to the laser.

## Model A: electronics under the plate

### Laser and Roland files

| Part | Picture (click to enlarge) | As made | Open it in |
|---|---|---|---|
| **Base plate**<br>Ø110, 3 mm plywood, ×1 | v1_base_plate_laser | [SVG](files/v1_base_plate_laser.svg){ download } | [Inkscape](files/src/projects/welcome-space/exports/inkscape/v1_base_plate_laser.svg){ download } · [Illustrator](files/src/projects/welcome-space/exports/illustrator/v1_base_plate_laser.svg){ download } · [DXF](files/src/projects/welcome-space/exports/dxf/v1_base_plate_laser.dxf){ download } · [Onshape sketch](files/src/projects/welcome-space/exports/onshape/v1_base_plate_profile.dxf){ download } |
| **Body panels**<br>3 mm plywood, ×3 | v1_panel_laser | [SVG](files/v1_panel_laser.svg){ download } | [Inkscape](files/src/projects/welcome-space/exports/inkscape/v1_panel_laser.svg){ download } · [Illustrator](files/src/projects/welcome-space/exports/illustrator/v1_panel_laser.svg){ download } · [DXF](files/src/projects/welcome-space/exports/dxf/v1_panel_laser.dxf){ download } · [Onshape sketch](files/src/projects/welcome-space/exports/onshape/v1_panel_profile.dxf){ download } |
| **Wings**<br>3 mm plywood, ×3 | v1_wing_laser | [SVG](files/v1_wing_laser.svg){ download } | [Inkscape](files/src/projects/welcome-space/exports/inkscape/v1_wing_laser.svg){ download } · [Illustrator](files/src/projects/welcome-space/exports/illustrator/v1_wing_laser.svg){ download } · [DXF](files/src/projects/welcome-space/exports/dxf/v1_wing_laser.dxf){ download } · [Onshape sketch](files/src/projects/welcome-space/exports/onshape/v1_wing_profile.dxf){ download } |
| **Comb test**<br>slot widths 3.00 to 3.30 mm | v1_comb_test_laser | [SVG](files/v1_comb_test_laser.svg){ download } | [Inkscape](files/src/projects/welcome-space/exports/inkscape/v1_comb_test_laser.svg){ download } · [Illustrator](files/src/projects/welcome-space/exports/illustrator/v1_comb_test_laser.svg){ download } · [DXF](files/src/projects/welcome-space/exports/dxf/v1_comb_test_laser.dxf){ download } |
| **Copper rails and patches**<br>Roland GS-24, 50 mm roll, 3 kits per band | v1_copper_rails_gs24_cut | [SVG](files/v1_copper_rails_gs24_cut.svg){ download } | [Inkscape](files/src/projects/welcome-space/exports/inkscape/v1_copper_rails_gs24_cut.svg){ download } · [Illustrator](files/src/projects/welcome-space/exports/illustrator/v1_copper_rails_gs24_cut.svg){ download } · [DXF](files/src/projects/welcome-space/exports/dxf/v1_copper_rails_gs24_cut.dxf){ download } |

### 3D printed parts

| Part | As made | Open it in |
|---|---|---|
| **Nose cone**<br>translucent PLA or PETG, ×1 | [STL](files/v1_nose_cone.stl){ download } · [OpenSCAD](files/v1_nose_cone.scad){ download } | [Onshape sketch](files/src/projects/welcome-space/exports/onshape/v1_nose_cone_profile.dxf){ download } · [View in 3D](viewer/index.html) |
| **Base diffuser**<br>translucent, ×1, shared by Model A and B | [STL](files/v1_diffuser.stl){ download } · [OpenSCAD](files/v1_diffuser.scad){ download } | [Onshape sketch](files/src/projects/welcome-space/exports/onshape/v1_diffuser_profile.dxf){ download } · [View in 3D](viewer/index.html) |

## Model B: LEDs outside

See [Model A or Model B?](models.md) for the differences and the tests.

### Laser and Roland files

| Part | Picture (click to enlarge) | As made | Open it in |
|---|---|---|---|
| **Base plate B**<br>Ø110, 3 panel slots, 3 wing slots, 2 wire holes | v1b_base_plate_laser | [SVG](files/v1b_base_plate_laser.svg){ download } | [Inkscape](files/src/projects/welcome-space/exports/inkscape/v1b_base_plate_laser.svg){ download } · [Illustrator](files/src/projects/welcome-space/exports/illustrator/v1b_base_plate_laser.svg){ download } · [DXF](files/src/projects/welcome-space/exports/dxf/v1b_base_plate_laser.dxf){ download } · [Onshape sketch](files/src/projects/welcome-space/exports/onshape/v1b_base_plate_profile.dxf){ download } |
| **Panel set B**<br>1 power panel + 2 plain panels | v1b_panels_set_laser | [SVG](files/v1b_panels_set_laser.svg){ download } | [Inkscape](files/src/projects/welcome-space/exports/inkscape/v1b_panels_set_laser.svg){ download } · [Illustrator](files/src/projects/welcome-space/exports/illustrator/v1b_panels_set_laser.svg){ download } · [DXF](files/src/projects/welcome-space/exports/dxf/v1b_panels_set_laser.dxf){ download } · [Onshape sketch](files/src/projects/welcome-space/exports/onshape/v1b_panels_set_profile.dxf){ download } |
| **Wings B**<br>3 mm plywood, ×3 | v1b_wing_laser | [SVG](files/v1b_wing_laser.svg){ download } | [Inkscape](files/src/projects/welcome-space/exports/inkscape/v1b_wing_laser.svg){ download } · [Illustrator](files/src/projects/welcome-space/exports/illustrator/v1b_wing_laser.svg){ download } · [DXF](files/src/projects/welcome-space/exports/dxf/v1b_wing_laser.dxf){ download } · [Onshape sketch](files/src/projects/welcome-space/exports/onshape/v1b_wing_profile.dxf){ download } |
| **Copper rails B**<br>2 rails 106 mm + patches, Roland GS-24 | v1b_copper_rails_gs24_cut | [SVG](files/v1b_copper_rails_gs24_cut.svg){ download } | [Inkscape](files/src/projects/welcome-space/exports/inkscape/v1b_copper_rails_gs24_cut.svg){ download } · [Illustrator](files/src/projects/welcome-space/exports/illustrator/v1b_copper_rails_gs24_cut.svg){ download } · [DXF](files/src/projects/welcome-space/exports/dxf/v1b_copper_rails_gs24_cut.dxf){ download } |

### 3D printed parts

| Part | As made | Open it in |
|---|---|---|
| **Nose cone B**<br>translucent, Ø66 base, ×1 | [STL](files/v1b_nose_cone.stl){ download } · [OpenSCAD](files/v1b_nose_cone.scad){ download } | [Onshape sketch](files/src/projects/welcome-space/exports/onshape/v1b_nose_cone_profile.dxf){ download } · [View in 3D](viewer/index.html?m=b) |
The diffuser is the same part as in Model A.

## Stickers and printable cards

| Part | Picture (click to enlarge) | As made | Open it in |
|---|---|---|---|
| **Sticker sheet**<br>Roland BN-20, print + cut, one per student | v1_sticker_sheet_print_cut | [SVG](files/v1_sticker_sheet_print_cut.svg){ download } | [Inkscape](files/src/projects/welcome-space/exports/inkscape/v1_sticker_sheet_print_cut.svg){ download } · [Illustrator](files/src/projects/welcome-space/exports/illustrator/v1_sticker_sheet_print_cut.svg){ download } · [DXF](files/src/projects/welcome-space/exports/dxf/v1_sticker_sheet_print_cut.dxf){ download } |
| **Troubleshooting card**<br>A6, Bug Hunter | v1_troubleshooting_card | [SVG](files/v1_troubleshooting_card.svg){ download } | [Inkscape](files/src/projects/welcome-space/exports/inkscape/v1_troubleshooting_card.svg){ download } · [Illustrator](files/src/projects/welcome-space/exports/illustrator/v1_troubleshooting_card.svg){ download } |
| **Student step card**<br>A4, picture-first | v1_student_card | [SVG](files/v1_student_card.svg){ download } | [Inkscape](files/src/projects/welcome-space/exports/inkscape/v1_student_card.svg){ download } · [Illustrator](files/src/projects/welcome-space/exports/illustrator/v1_student_card.svg){ download } |

## Test logs

| File | What it is |
|---|---|
| [bench-test-template.csv](files/bench-test-template.csv){ download } | Electronics bench test log |
| [pilot-log-template.csv](files/pilot-log-template.csv){ download } | Pilot lesson log |
| [ab-test-template.csv](files/ab-test-template.csv){ download } | Model A / B build and test log |
| [ab-decision-template.csv](files/ab-decision-template.csv){ download } | Model A / B weighted decision table |

!!! note "Laser colors"
    Red hairline = cut, black = engrave. In the sticker sheet, magenta is the BN-20 cut line.

## 3D models to look at

Open them in any 3D viewer or slicer preview. They are **simplified previews, not for printing**: slots in the nose cone and the diffuser window are missing. Print from the STL files above.

| Model | File | View online |
|---|---|---|
| Model A, whole ship | [v1_assembly_preview.stl](https://raw.githubusercontent.com/HisarCS/fablibrary/main/projects/welcome-space/3d/preview/v1_assembly_preview.stl){ download } | [3D explorer](viewer/index.html) |
| Model B, whole ship | [v1b_assembly_preview.stl](https://raw.githubusercontent.com/HisarCS/fablibrary/main/projects/welcome-space/3d/preview/v1b_assembly_preview.stl){ download } | [3D explorer](viewer/index.html?m=b) |

In the explorer you can turn the ship, pull it apart, cut it in half and switch between Model A and Model B.

## Game

[Play Mission Control](play.md){ .md-button } A game for iPad that teaches the machines, the circuit, the fit and the build order.

## Sources and tools

Everything above is generated from these files. To change a design, change a number here, then rebuild. Do not edit the generated files by hand.

| File | What it does |
|---|---|
| [generators/build.py](https://raw.githubusercontent.com/HisarCS/fablibrary/main/projects/welcome-space/generators/build.py) | Rebuilds every Model A file |
| [generators/model_b.py](https://raw.githubusercontent.com/HisarCS/fablibrary/main/projects/welcome-space/generators/model_b.py) | Builds every Model B file |
| [generators/model3d.py](https://raw.githubusercontent.com/HisarCS/fablibrary/main/projects/welcome-space/generators/model3d.py) | Builds the Model A 3D preview and explorer data |
| [generators/printables.py](https://raw.githubusercontent.com/HisarCS/fablibrary/main/projects/welcome-space/generators/printables.py) | Copper band, sticker sheet, troubleshooting card |
| [3d/v1_nose_cone.scad](files/v1_nose_cone.scad){ download }, [v1_diffuser.scad](files/v1_diffuser.scad){ download }, [v1b_nose_cone.scad](files/v1b_nose_cone.scad){ download } | The parametric 3D parts |
| [kit-list.md](kit-list.md) | Parts per kit and the parameter map |

Repository scripts: `svg_tool.py` (prepare and check SVG files), `export_formats.py` (Inkscape, Illustrator, DXF, Onshape), `export_stl.sh` (print STL files), `check_stl.py` (check an STL), `export_test_prints.sh` (tolerance test prints). They are in the `scripts` folder of the [repository](https://github.com/HisarCS/fablibrary/tree/main/scripts) and in the ZIP above.

## Drawings

### Base plate and diffuser
Base plate and diffuser

### Panel and nose cone
Panel and nose cone

### Wing
Wing

### Model B
Model B drawing

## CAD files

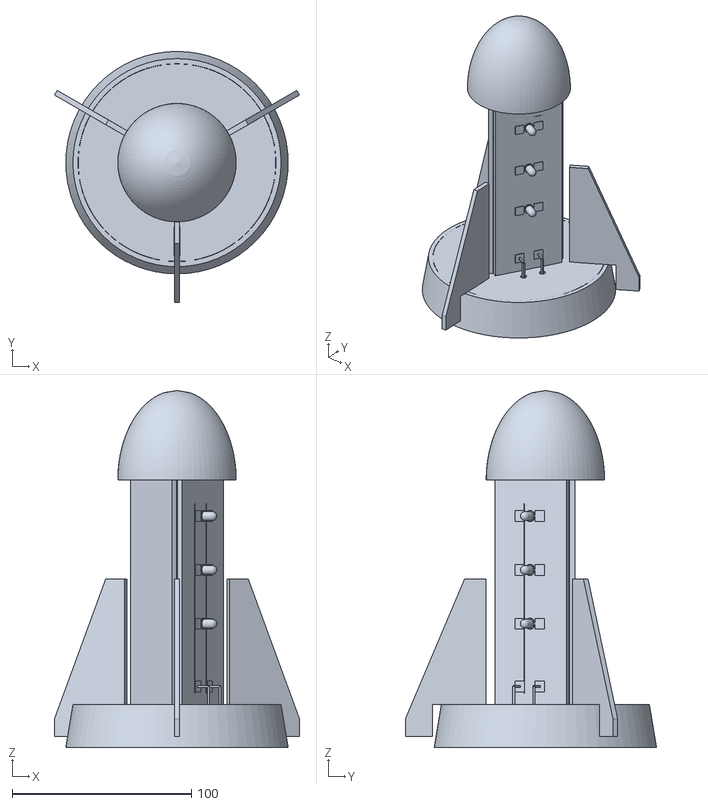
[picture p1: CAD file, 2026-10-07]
projects/welcome-space/3d/preview/v1b_assembly_preview.stl
136.6 x 140.0 x 199.0

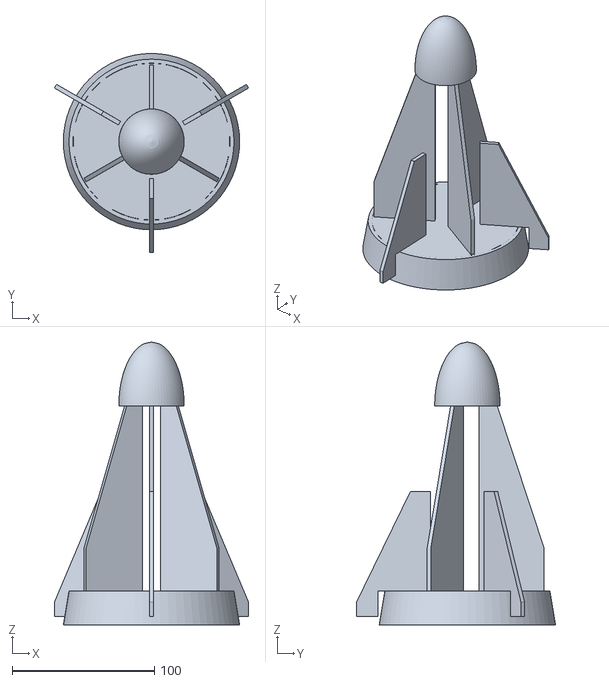
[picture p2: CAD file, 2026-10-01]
projects/welcome-space/3d/preview/v1_assembly_preview.stl
136.6 x 140.0 x 199.0

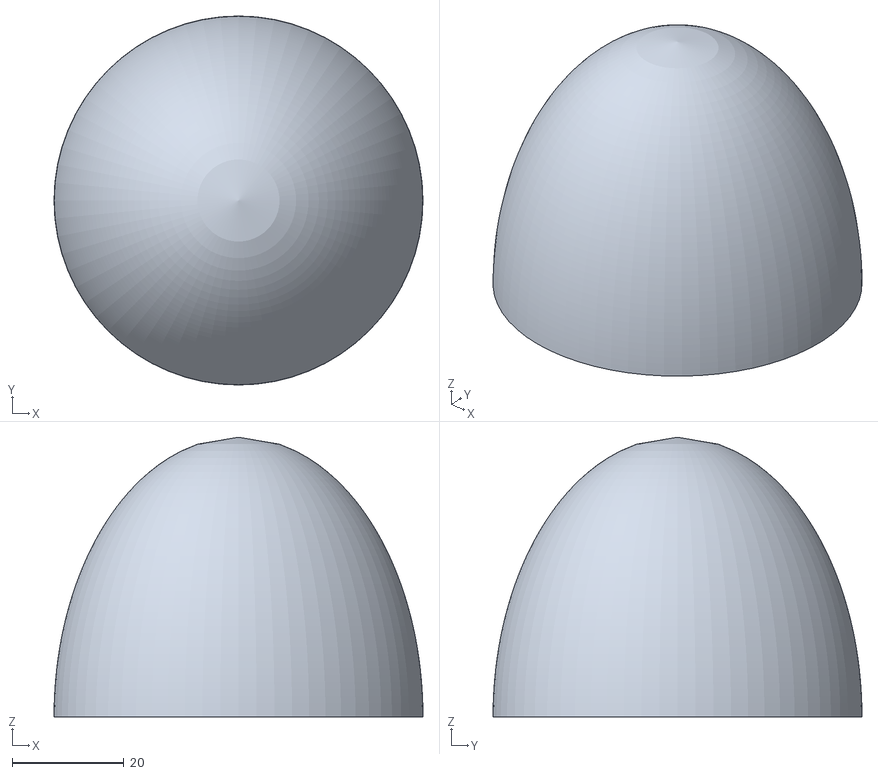
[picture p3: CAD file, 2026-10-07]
projects/welcome-space/3d/preview/v1b_nose_cone_preview.stl
66.0 x 66.0 x 50.0

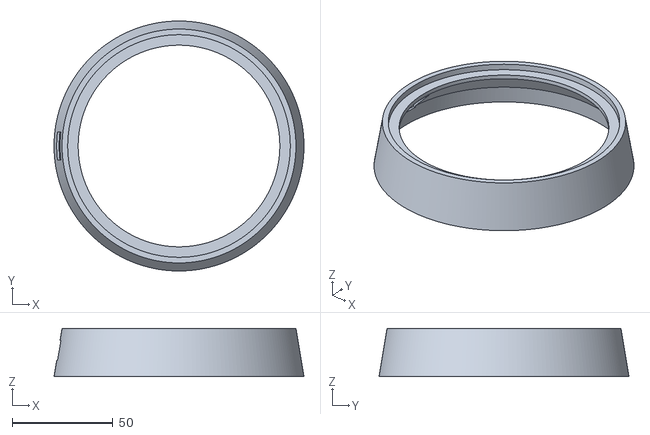
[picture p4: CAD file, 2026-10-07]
projects/welcome-space/3d/stl/v1_diffuser.stl
124.0 x 124.0 x 24.0

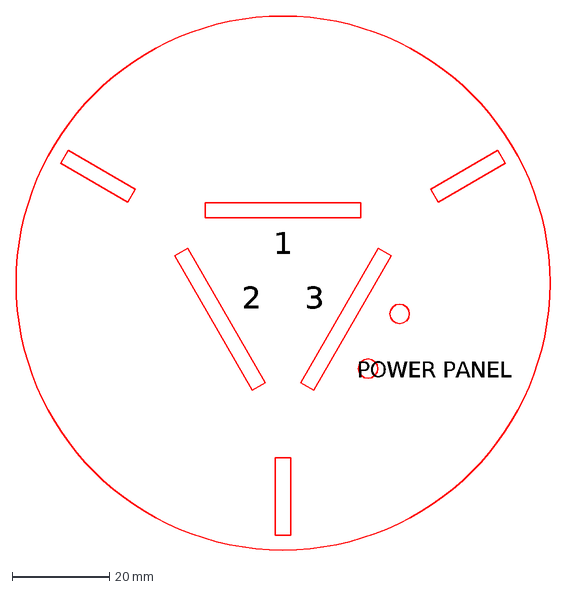
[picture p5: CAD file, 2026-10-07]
projects/welcome-space/exports/dxf/v1b_base_plate_laser.dxf
1
2
3
POWER PANEL

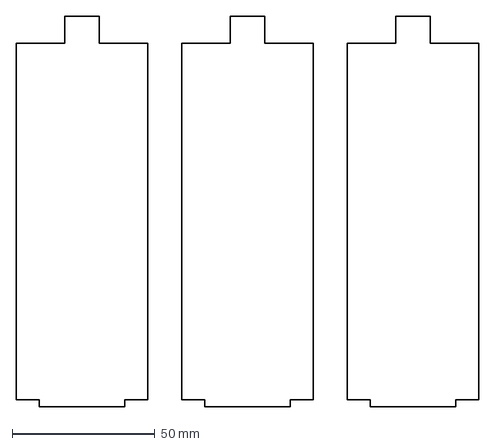
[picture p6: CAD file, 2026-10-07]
projects/welcome-space/exports/onshape/v1b_panels_set_profile.dxf
162.0 x 137.0 mm

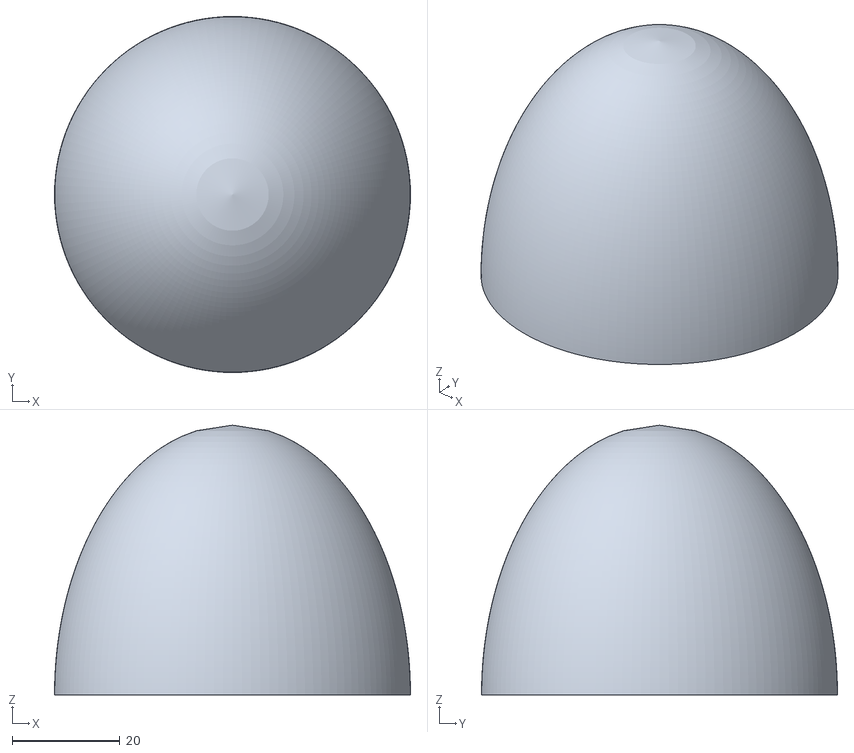
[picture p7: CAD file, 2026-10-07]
projects/welcome-space/3d/stl/v1b_nose_cone.stl
66.0 x 66.0 x 50.0

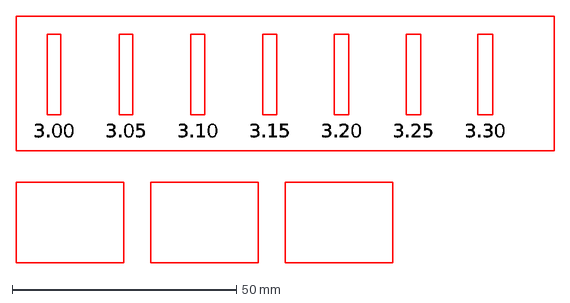
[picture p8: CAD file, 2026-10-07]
projects/welcome-space/exports/dxf/v1_comb_test_laser.dxf
3.00
3.05
3.10
3.15
3.20
3.25
3.30

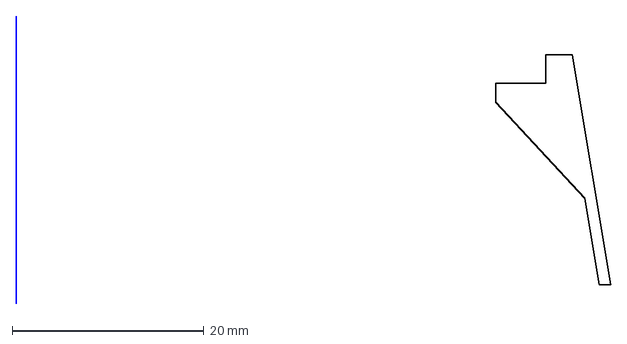
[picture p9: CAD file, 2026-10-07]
projects/welcome-space/exports/onshape/v1_diffuser_profile.dxf
62.0 x 30.0 mm

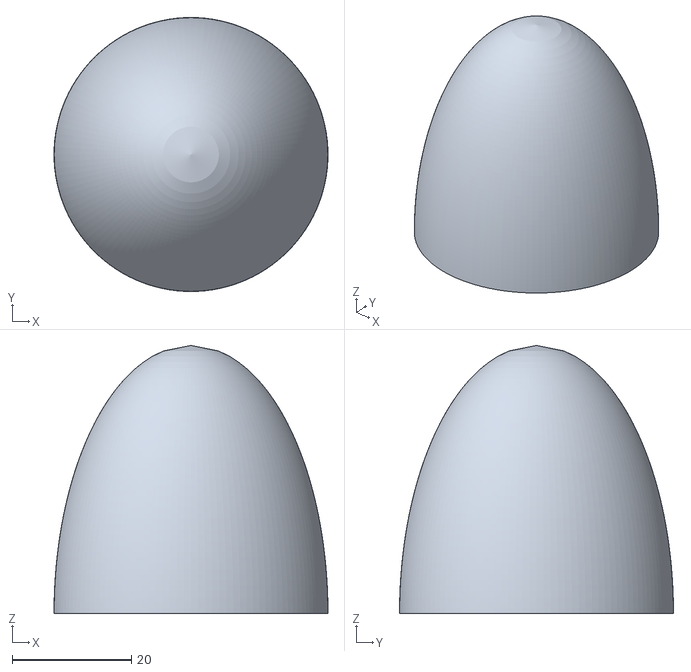
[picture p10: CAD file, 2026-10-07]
projects/welcome-space/3d/stl/v1_nose_cone.stl
46.0 x 46.0 x 45.0

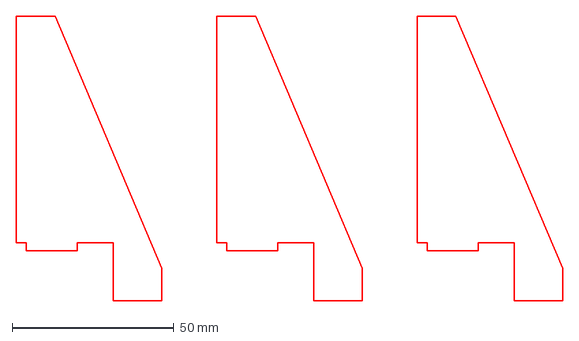
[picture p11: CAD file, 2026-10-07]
projects/welcome-space/exports/dxf/v1b_wing_laser.dxf
169.0 x 88.0 mm

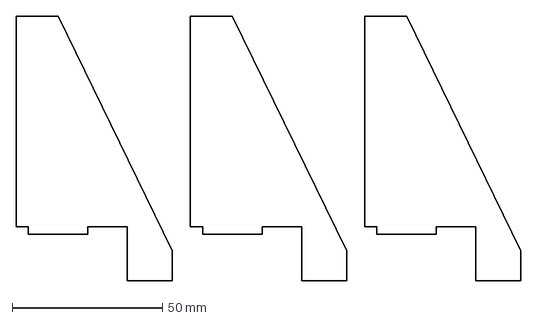
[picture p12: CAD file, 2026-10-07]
projects/welcome-space/exports/onshape/v1_wing_profile.dxf
168.0 x 88.0 mm

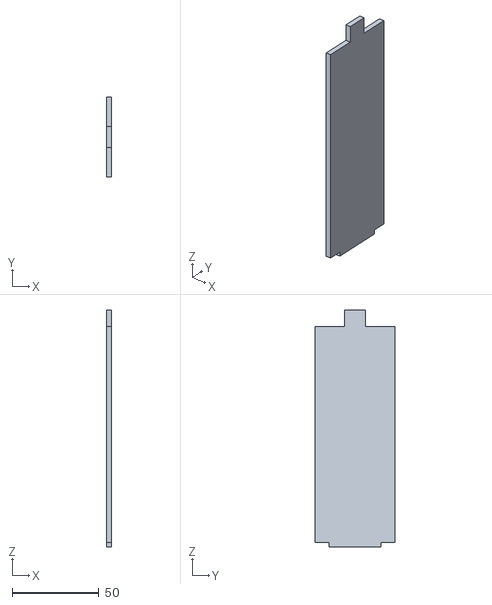
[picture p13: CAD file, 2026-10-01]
projects/welcome-space/3d/preview/v1b_panel_preview.stl
3.00 x 46.0 x 137.0

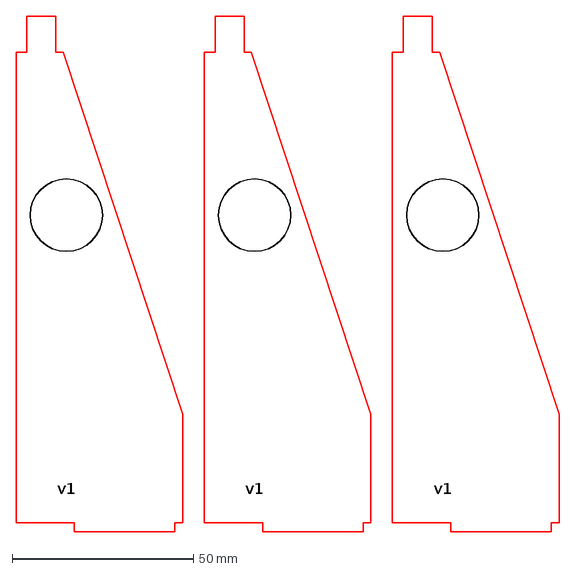
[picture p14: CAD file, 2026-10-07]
projects/welcome-space/exports/dxf/v1_panel_laser.dxf
v1

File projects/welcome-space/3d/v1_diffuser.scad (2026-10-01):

// v1 spaceship - exhaust diffuser (translucent PLA/PETG)
// Units: mm. z=0 is the table, z=24 is the top (flush with the plate's top face).
// Print: as modeled (wide base on the bed, rim up), no supports (the ledge underside is chamfered), 3 perimeters.

// ---- main parameters ----
H        = 24;     // total height
Rtop     = 58;     // top outer radius (O116)
Rbot     = 62;     // bottom outer radius (O124)
wall     = 1.2;    // sloped wall thickness
pocketD  = 110.4;  // plate pocket diameter -> test print 110.25 / 110.40 / 110.55
pocketH  = 3;      // pocket depth (plate thickness)
ledgeR   = 50;     // support ledge inner radius (O100) - electronics stay inside
ledgeT   = 2;      // support ledge thickness
chamferDz = 10;    // height of the 45-degree underside of the ledge (lets it print without supports)

// ---- switch / battery access window (adjust when holder sample arrives) ----
winOn    = true;
winAng   = 180;    // window direction (deg). Point it at the holder's switch side.
winW     = 14;     // window width
winZ0    = 8;      // window bottom edge (from table)
winZ1    = 18;     // window top edge (must stay below the ledge: < H-pocketH-ledgeT = 19)

$fn = 180;

rp = pocketD/2;
zl = H - pocketH;          // height where the plate sits (21)
zb = zl - ledgeT;          // underside of the ledge (19)
function rout(z) = Rbot + (Rtop-Rbot)*z/H;   // outer wall radius
zc    = zb - chamferDz;     // where the chamfer starts on the inner wall
rin_c = rout(zc) - wall;

// The ledge underside is a ~45 degree slope instead of a flat shelf: no supports needed.
profile = [
  [rp, H], [Rtop, H], [Rbot, 0], [Rbot-wall, 0],
  [rin_c, zc], [ledgeR, zb], [ledgeR, zl], [rp, zl]
];

difference() {
  rotate_extrude() polygon(profile);
  if (winOn)
    rotate([0,0,winAng])
      translate([ledgeR-6, -winW/2, winZ0]) cube([Rbot-ledgeR+12, winW, winZ1-winZ0]);
}

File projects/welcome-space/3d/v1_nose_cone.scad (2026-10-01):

// v1 spaceship - nose cone (translucent PLA/PETG)
// Units: mm. Print base down, no supports needed.
R      = 23;    // base outer radius (O46)
H      = 45;    // height
wall   = 1.2;   // shell wall (0.4 nozzle: 3 perimeters)
hubH   = 12;    // hub height
hubRin = 8;     // hub inner radius (O16 hole)
slotW  = 3.3;   // slot width for panel tab (test 3.2/3.3/3.4)
slotR0 = 10.5;  // slot inner start radius
slotR1 = 19.5;  // slot outer end radius
slotD  = 11;    // slot depth (tab is 10)
N      = 48;    // profile resolution
$fn    = 120;

function prof(r, h) = concat([[0,0]], [for (i=[0:N]) let(z=h*i/N) [r*sqrt(max(0,1-pow(z/h,2))), z]]);

module solid(r, h) { rotate_extrude() polygon(prof(r, h)); }

module shell() { difference() { solid(R, H); translate([0,0,-0.01]) solid(R-wall, H-wall); } }

module hub() {
  difference() {
    intersection() { solid(R-wall+0.01, H-wall); cylinder(r=R, h=hubH); }
    translate([0,0,-1]) cylinder(r=hubRin, h=hubH+2);
    for (a=[90,210,330]) rotate([0,0,a])
      translate([slotR0, -slotW/2, -1]) cube([slotR1-slotR0, slotW, slotD+1]);
  }
}

union() { shell(); hub(); }

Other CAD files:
projects/welcome-space/3d/preview/v1b_diffuser_preview.stl
projects/welcome-space/exports/onshape/v1b_wing_profile.dxf
projects/welcome-space/3d/preview/v1b_wing_preview.stl
projects/welcome-space/exports/dxf/v1b_copper_rails_gs24_cut.dxf
projects/welcome-space/3d/v1b_nose_cone.scad
projects/welcome-space/3d/preview/v1_base_plate_preview.stl
projects/welcome-space/3d/preview/v1_nose_cone_preview.stl
projects/welcome-space/3d/preview/v1_panel_preview.stl
projects/welcome-space/3d/preview/v1_wing_preview.stl
projects/welcome-space/3d/preview/v1b_base_plate_preview.stl
projects/welcome-space/exports/dxf/v1_base_plate_laser.dxf
projects/welcome-space/exports/dxf/v1_copper_rails_gs24_cut.dxf
projects/welcome-space/exports/dxf/v1_sticker_sheet_print_cut.dxf
projects/welcome-space/exports/dxf/v1_wing_laser.dxf
projects/welcome-space/exports/dxf/v1b_panels_set_laser.dxf
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

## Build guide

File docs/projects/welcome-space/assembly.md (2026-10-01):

# Assembly

Assembly sequence

1. Stickers: on panels and wings while they are flat
2. Electronics: plate upside down (bottom face up) – holder, 2 copper rails, 3 LEDs
3. Test: insert battery, ON. If not lit, follow the 5-step troubleshooting
4. Panels ×3: into the long slots on the top face of the plate
5. Plate into diffuser: electronics facing down
6. Nose cone: onto the top tabs of the 3 panels
7. Wings ×3: into the short slots
8. Dark room: everyone switches ON together

!!! warning "To be tested in the pilot"
    The order of steps 4-5-6. Alternative: panels into the nose cone first, then everything into the plate.

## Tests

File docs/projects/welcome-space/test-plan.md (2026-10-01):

# Test plan

Every test is recorded on GitHub via **Issues → Test result**.

| # | Stage | Gate criterion | Parameter to change |
|---|---|---|---|
| 1 | Electronics bench test | 10/10 circuits work, 3 LEDs clearly visible | LED type, resistor |
| 2 | Copper tape / GS-24 | 10 cuts, 10 clean peels | – |
| 3 | Comb test | Fits by a child's hand without force or wobble | `SLOT_W` |
| 4 | 3D print | Nose cone and diffuser fit, glow in the dark | `slotW`, `pocketD` |
| 5 | Stickers | Dry, clean adhesion | – |
| 6 | Integrated prototype | An adult assembles it in 15–20 min | – |
| 7 | Pilot (6–8 children) | At least 80% success within 60 min | Assembly order |

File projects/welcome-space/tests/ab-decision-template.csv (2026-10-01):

priority | weight | score_A_1to5 | score_B_1to5 | weighted_A | weighted_B | evidence
1 Reliability | 8
2 A child can build it alone | 7
3 Fits in 60 minutes | 6
4 Easy to troubleshoot | 5
5 Scales to 140 ships | 4
6 FabLab processes visible | 3
7 Looks great | 2
8 Makes children curious about CAD | 1
TOTAL

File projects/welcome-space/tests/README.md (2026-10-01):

# Tests

Open a GitHub Issue for every test (Test result form). Add photos here as `YYYY-MM-DD_test-name.jpg`. No student faces or names.

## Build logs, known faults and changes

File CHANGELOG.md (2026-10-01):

# Changelog

## Welcome Space

### Model B (draft)
- Added Model B ("LEDs outside"): closed three-panel body, LEDs and straight copper rails on one power panel, 66 mm nose cone. Model A is unchanged. Files: `laser/v1b_*.svg`, `drawings/v1b_drawing.svg`, `3d/v1b_nose_cone.scad`, preview meshes and a Model A / Model B switch in the 3D explorer.
- Added the "Model A or Model B?" page with the comparison tests, a weighted decision table and an A/B decision issue form. Tests are tracked in the `[A/B]` issues.

### Diffuser: supportless ledge (draft)
- `v1_diffuser.scad`: the ledge underside is now a 45-degree chamfer instead of a flat shelf, so the diffuser prints without supports. New parameter `chamferDz` = 10 mm. The switch window cut now spans the wall from `ledgeR-6` to `Rbot+6`. `pocketD` is unchanged (110.4, still to be confirmed). Related test: [#4](https://github.com/HisarCS/fablibrary/issues/4).
- `v1_base_diffuser_drawing.svg` and the preview meshes regenerated from the same numbers.

### Site update
- Hero and personalization illustrations now show the stickers applied; the sticker sheet is shown on the project page.
- Added GS-24 copper band, BN-20 sticker sheet, troubleshooting card, bench test log template and an assumptions log (all parts assumed delivered for planning).
- Added a first-week task plan and a script that creates its GitHub issues.
- Added finished-ship illustrations (day, dark room, personalization), safety page, kit list page, real file downloads and a mission roadmap.

### v1-proto1 (draft)
- First design set: base plate (Ø110, 3 panel slots + 3 wing slots), panel ×3, wing ×3, nose cone, diffuser, comb test.
- Electronics: CR2032 holder with cover and switch, 2 copper rails, 3 LEDs, all under the base plate.
- All tolerances are estimates: `SLOT_W=3.1`, `slotW=3.3`, `pocketD=110.4`. To be updated after testing.

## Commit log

2026-10-01 Add Welcome Space v1-proto1 and FabLibrary site
    [v1_diffuser.scad, v1_nose_cone.scad]
2026-10-01 Add GS-24 band, sticker sheet, troubleshooting card, assumptions log
    [bench-test-template.csv]
2026-10-01 Add student step card and pilot observation form
    [pilot-log-template.csv]
2026-10-01 Add 3D explorer and preview STL meshes
    [v1_assembly_preview.stl, v1_base_plate_preview.stl, v1_diffuser_preview.stl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]
2026-10-01 Print the diffuser without supports; add STL check and test-print export
    [v1_assembly_preview.stl, v1_diffuser.scad, v1_diffuser_preview.stl]
2026-10-01 Add Model B (LEDs outside) and A/B comparison
    [ab-decision-template.csv, ab-test-template.csv, v1b_assembly_preview.stl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]
2026-10-02 Add print STLs: export script, site downloads and docs
    [v1_diffuser.stl, v1_nose_cone.stl, v1b_nose_cone.stl]
2026-10-07 Add Source files page with one-click ZIP
    New MkDocs hook builds sources.md and a ZIP of all editable files on each
    build; generated output is git-ignored. Link it from the nav and parts page,
    and refresh the print STLs.
    [v1_nose_cone.stl, v1b_nose_cone.stl]
2026-10-07 Add SVG tools and Inkscape/Illustrator/DXF/Onshape exports
    svg_tool.py names Inkscape layers and checks files before cutting;
    export_formats.py writes projects/*/exports/. build.py now runs model_b.py
    and svg_tool.py prepare. New pages: Edit the SVG files, Files for Inkscape,
    Illustrator and Onshape.
    [v1_base_plate_laser.dxf, v1_base_plate_profile.dxf, v1_comb_test_laser.dxf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]
2026-10-07 Export binary STLs, keep web thumbnails out of the ZIP, group nav
    export_stl.sh converts each STL to binary via scripts/stl_to_binary.py.
    sources_page.py still copies exports/web/ for the page thumbnails but leaves
    it out of the ZIP and the file list. Welcome Space nav is split into Students
    and Team.
    [v1_diffuser.stl, v1_nose_cone.stl, v1b_nose_cone.stl]
